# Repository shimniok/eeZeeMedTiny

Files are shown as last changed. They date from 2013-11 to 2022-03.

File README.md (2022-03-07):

# eeZeeMedTiny
A breadboard breakout / target board for ATtiny84 family

The smallest breakout & target board for the 14-pin ATtiny84, including AVR ISP header, reset switch and pull-up resistor,
and bypass caps. Step up to an ATtiny84 for more power and 6 more pins.

Easy to breadboard, prototype and program ATtiny84 with eeZee Medium Tiny. 

[For sale on Tindie.com](https://www.tindie.com/products/bot_thoughts/attiny84-development-board/)

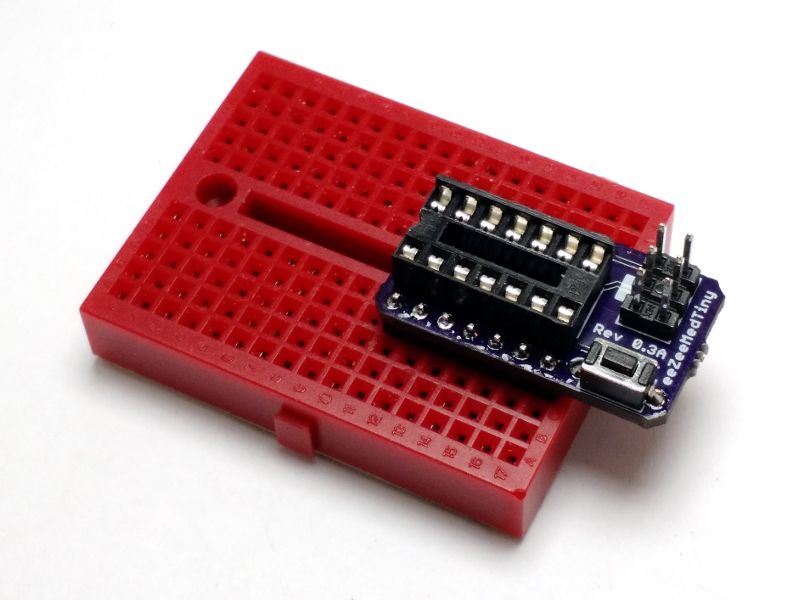
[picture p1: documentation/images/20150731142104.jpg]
top view


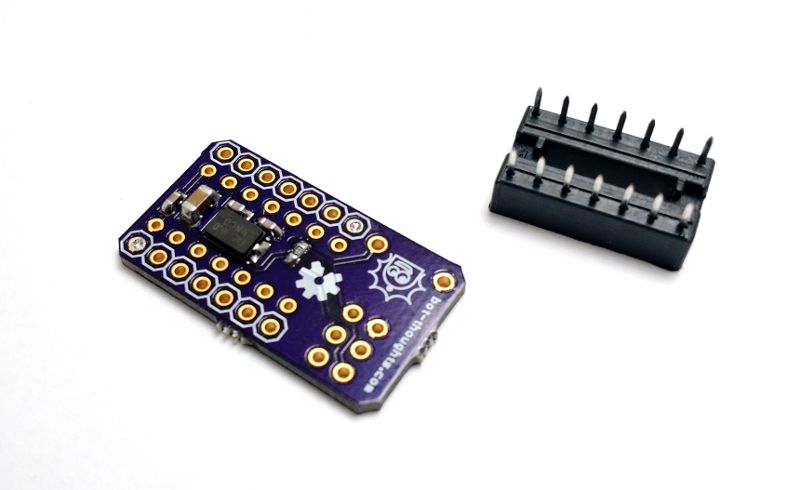
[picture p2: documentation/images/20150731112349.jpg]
bottom view


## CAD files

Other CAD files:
electronics/eeZee_medium_tiny.skp

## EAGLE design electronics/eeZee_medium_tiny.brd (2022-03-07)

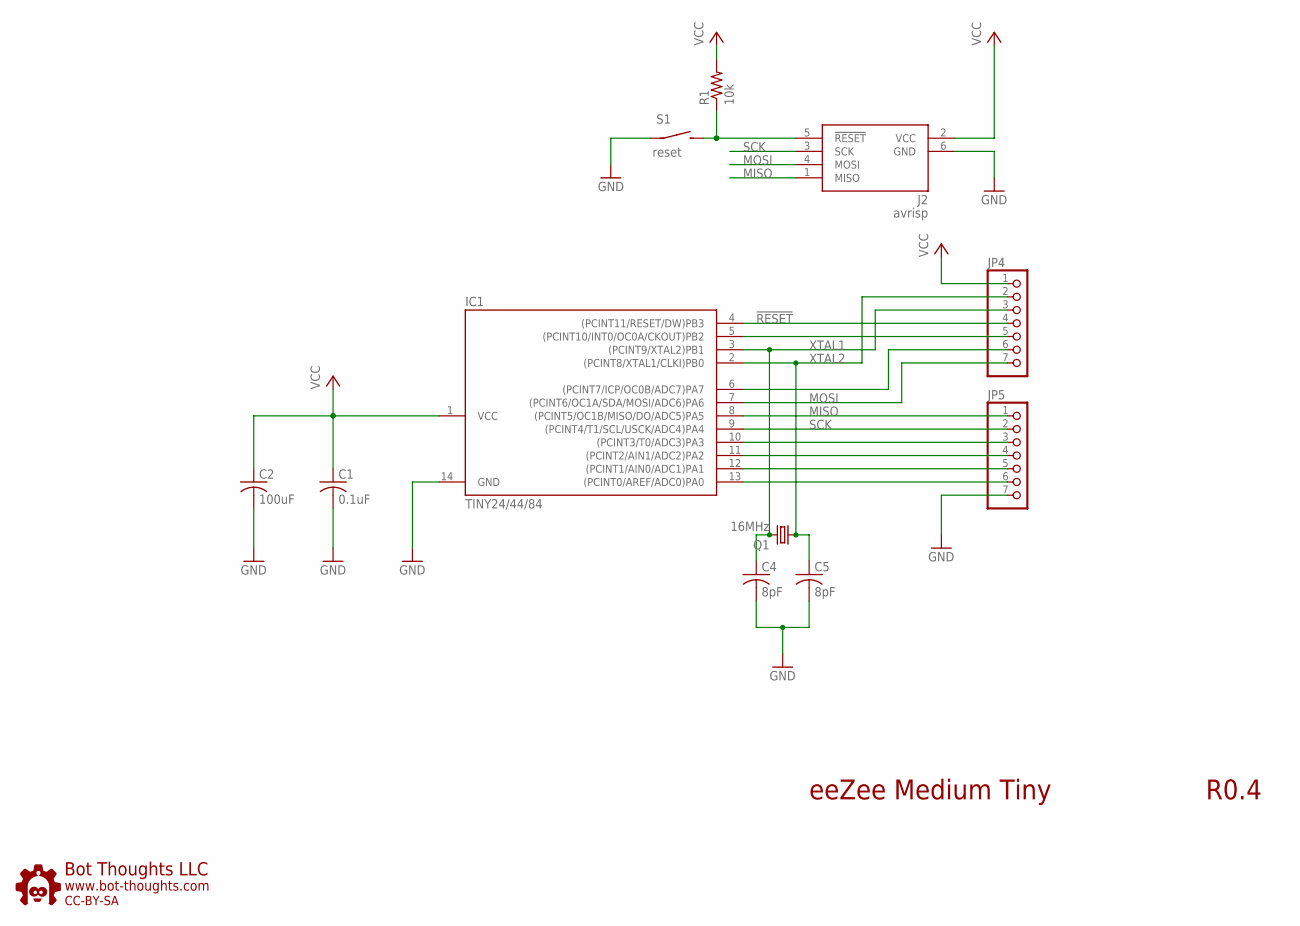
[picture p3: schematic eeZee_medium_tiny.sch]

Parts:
C1: 0.1uF; C0603; PARTNO 0603YC104KAT2A
C2: 100uF; C1206; PARTNO MCTT21X106M6R3CT
C4, C5: 8pF; C0603; PARTNO 0603YC104KAT2A
IC1: TINY24/44/84; DIL14
J2: avrisp; CON6P2R
JP4, JP5: PINHD-1X07_2.54-S; 1X07-S
Q1: 16MHz; NDK_2PAD_5X3
R1: 10k; R0603; PARTNO ERJ-3GEYJ103V
S1: reset; 6MMTACTILE_RECT
U$1: BTLOGO-LOGO-SM; BTLOGOS

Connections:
!RESET: IC1.4 ((PCINT11/RESET/DW)PB3), J2.5 (!RESET), JP4.4, R1.1, S1.P$2 (S)
GND: C1.2, C2.2, C4.2, C5.2, IC1.14 (GND), J2.6 (GND), JP5.7, S1.P$1
MISO: IC1.8 ((PCINT5/OC1B/MISO/DO/ADC5)PA5), J2.1 (MISO), JP5.1
MOSI: IC1.7 ((PCINT6/OC1A/SDA/MOSI/ADC6)PA6), J2.4 (MOSI), JP4.7
unnamed: IC1.5 ((PCINT10/INT0/OC0A/CKOUT)PB2), JP4.5
unnamed: IC1.6 ((PCINT7/ICP/OC0B/ADC7)PA7), JP4.6
unnamed: IC1.10 ((PCINT3/T0/ADC3)PA3), JP5.3
unnamed: IC1.11 ((PCINT2/AIN1/ADC2)PA2), JP5.4
unnamed: IC1.12 ((PCINT1/AIN0/ADC1)PA1), JP5.5
unnamed: IC1.13 ((PCINT0/AREF/ADC0)PA0), JP5.6
SCK: IC1.9 ((PCINT4/T1/SCL/USCK/ADC4)PA4), J2.3 (SCK), JP5.2
VCC: C1.1, C2.1, IC1.1 (VCC), J2.2 (VCC), JP4.1, R1.2
XTAL1: C5.1, IC1.2 ((PCINT8/XTAL1/CLKI)PB0), JP4.2, Q1.P$1 (1)
XTAL2: C4.1, IC1.3 ((PCINT9/XTAL2)PB1), JP4.3, Q1.P$2 (2)

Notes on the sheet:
eeZee Medium Tiny
R0.4

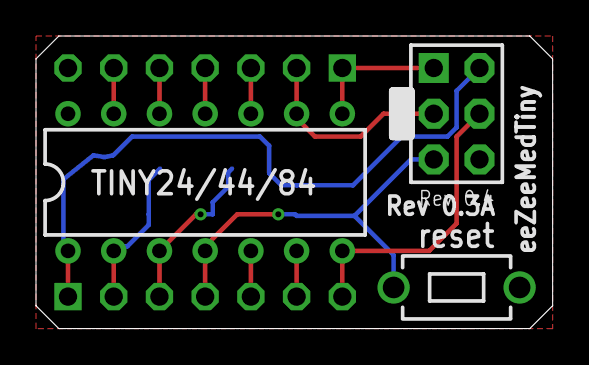
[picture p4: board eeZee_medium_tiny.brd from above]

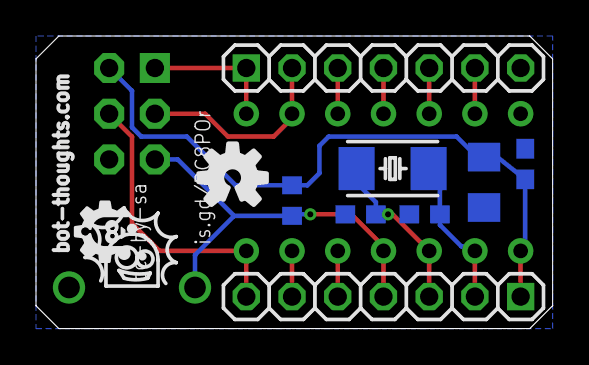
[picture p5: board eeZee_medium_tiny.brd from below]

Board: 2 copper layers, 28.7 x 16.3 mm, 12 parts (9 on the bottom side), 14 nets.

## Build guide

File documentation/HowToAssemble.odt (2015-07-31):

Assembly Instructions for eeZee Medium Tiny

Assembling your eeZee Medium Tiny is easy. And, you can learn how to solder at the same time. Review Sparkfun's Soldering Tutorial (https://learn.sparkfun.com/tutorials/how-to-solder---through-hole-soldering) if you need to. Here's a helpful info-graphic from the tutorial:

Illustration 1: https://learn.sparkfun.com/tutorials/how-to-solder---through-hole-soldering

# You'll need

- Soldering iron, 40W
- Sponge to clean the iron (I recommend a brass sponge)
- Workbench with plenty of light
- Ventilation since breathing flux fumes is irritating
- Soldering surface (e.g., marble tile sample)
- Rosin core solder 0.022” or 0.032” diameter
- Kester #2331-ZX flux pen (optional)

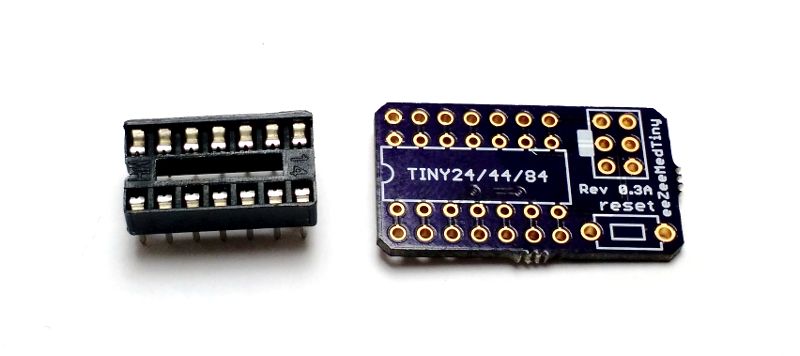
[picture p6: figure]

IC Socket

Apply flux pen or flux paste to the pin pads, top and bottom.

Match the notch on the socket with the silkscreen on the board

Insert the socket and flip the board and socket upside down

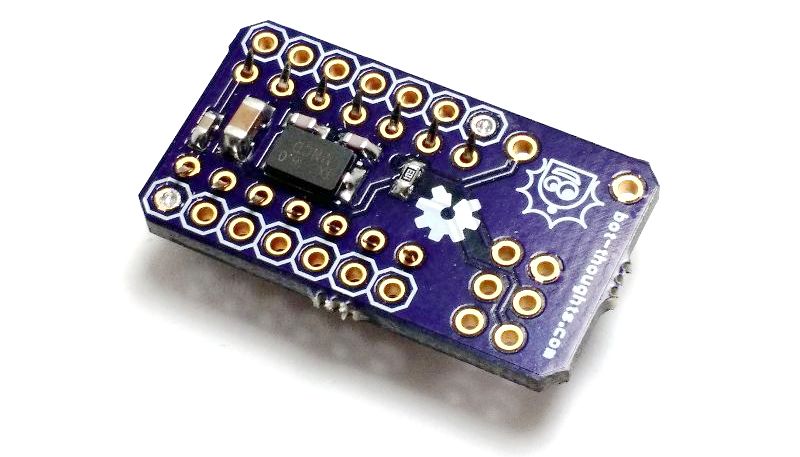
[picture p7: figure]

Bend the socket pins outward to help hold the socket and board together

Solder a pin in one corner, then a pin in the opposite corner

Solder the remaining pins

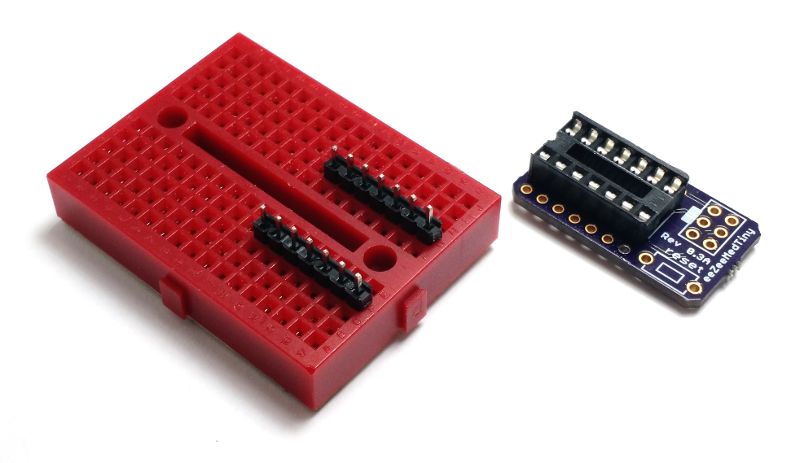
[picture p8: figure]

Pin Headers

Stick the two 4-pin headers into your breadboard, long side down, with 4 rows between

Apply flux to the outer pin header pads

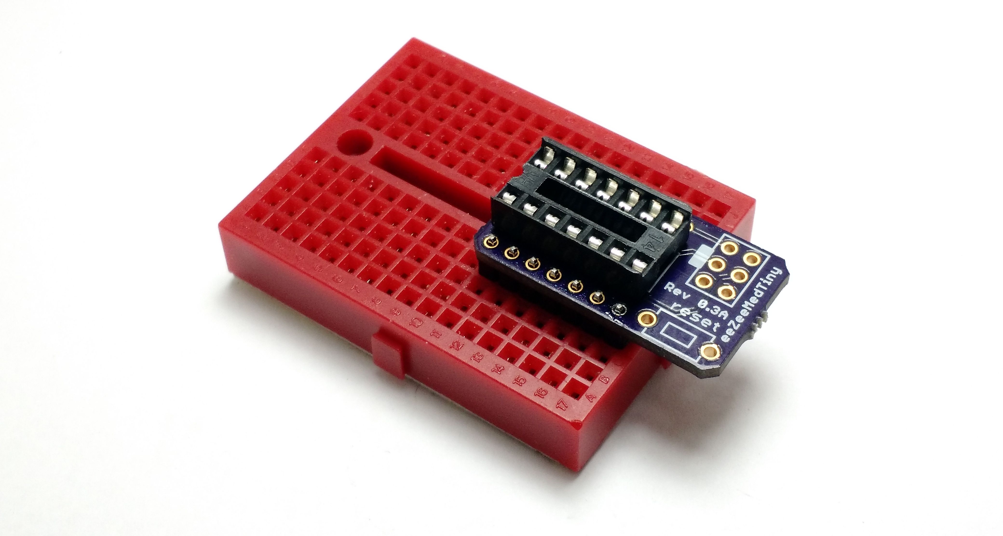
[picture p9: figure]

Place eeZeeTiny onto to pin headers

Holding the board in place, solder one of the pins on each pin header

Now solder the rest of the pins

ISP Header

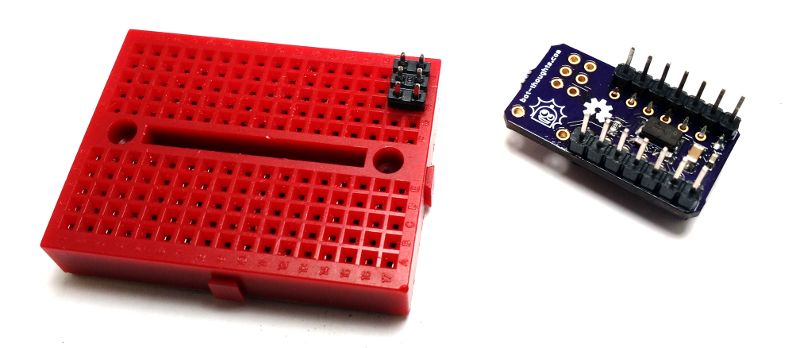
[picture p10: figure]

Install the 2x3 ISP header into the breadboard, long side down

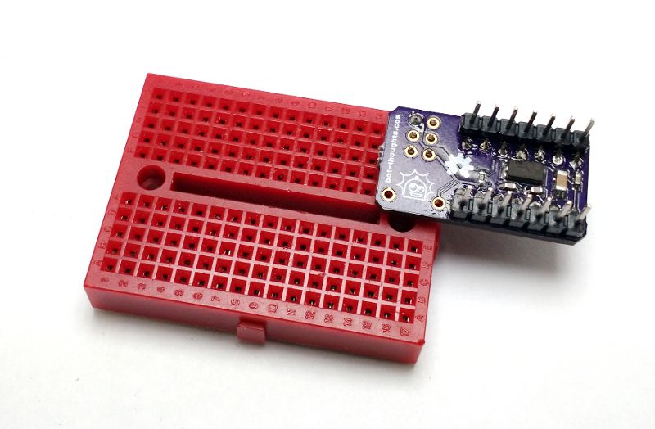
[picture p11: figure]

Flip the board upside down and place the board onto the pin header

Hold down the board and solder one pin

Solder the remaining pins.

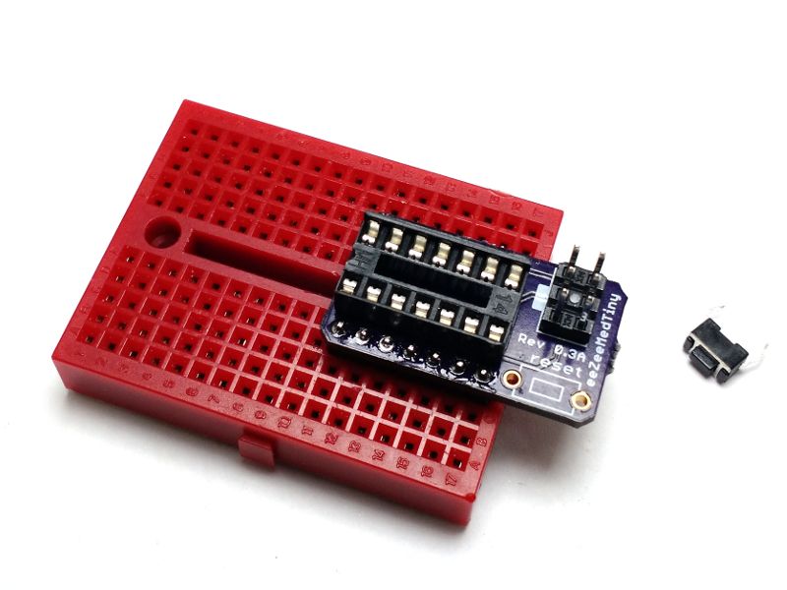
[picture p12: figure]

Reset Switch

Insert the board back into the breadboard, right side up

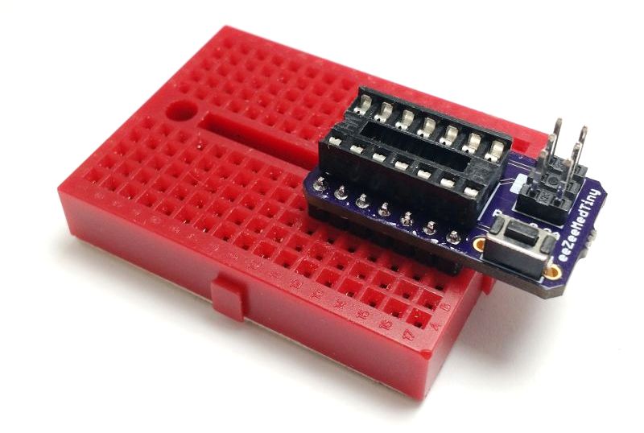
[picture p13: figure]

Install the reset switch

Solder the reset switch pins on the top side

Flip the board upside down and solder the reset switch on the bottom side

Cleanup

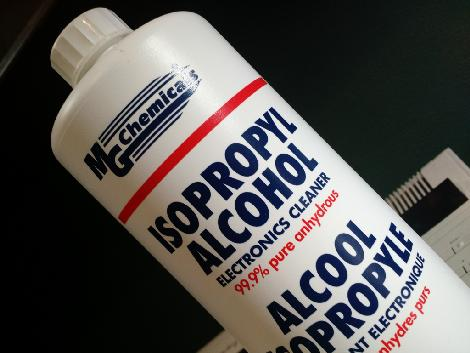
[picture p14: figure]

You'll want to remove the rosin and flux

I usually just use isopropyl alcohol and an old toothbrush

You can also buy chemicals specifically for removing flux and rosin

eeZeeTiny Assembly Instructions

www.bot-thoughts.com Page 4 / 4 Bot Thoughts LLC

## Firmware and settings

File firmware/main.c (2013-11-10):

/** ATtiny84 test
 * 
 * Author: Michael Shimniok (www.bot-thoughts.com)
 * Description: Sequentially turns on a single pin on PA0-7 and PB0-2 (PB3 is reset)
 *
 */
#include <avr/io.h>
#include <avr/interrupt.h>
#include <util/delay.h>

int main()
{
  char i;

  PORTA=0;
  PORTB=0;
  DDRA=0xff;   // All PORTA as output
  DDRB=0x07;   // PB0-2, PB3 is reset

  while (1) {
    for (i = 0 ; i < 8; i++) {
      PORTA = (1 << i);
      _delay_ms(300);
    }
    PORTA = 0;

    for (i = 2; i < 3; i++) {
      PORTB = (1 << i);
      _delay_ms(300);
    }
    PORTB = 0;
  }

}

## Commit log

2013-01-08 Initial revision
    [eeZee_big_tiny.brd, eeZee_big_tiny.sch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]
2013-01-08 Renamed files
    [eeZee_medium_tiny.brd]
2013-01-08 Minor board tweaks
    [eeZee_medium_tiny.brd]
2013-08-06 Rev 0.2 as ordered, mitered corners, flipped tantalum and added polarity silk screen, changed location of caps/crystals for easier assembly, shrunk board size.
    [eeZee_medium_tiny.brd, eeZee_medium_tiny.sch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]
2013-11-10 Created electronics and firmware directories so I could host example code.
    [eeZee_medium_tiny.brd, eeZee_medium_tiny.sch, eeZee_medium_tiny.skp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]
2014-04-15 Revised pads for IC, revised 10uF filtering cap footprint to 1206.
    [eeZee_medium_tiny.brd, eeZee_medium_tiny.sch]
2014-04-15 Removed extraneous silkscreen
    [eeZee_medium_tiny.brd]
2014-10-17 Changed spacing to 10mil/8mil, relocated too-close traces, relocated via
    [eeZee_medium_tiny.brd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]
2015-07-31 Added assembly instructions
2022-03-07 update logo, silk, add help url
    [eeZee_medium_tiny.brd, eeZee_medium_tiny.sch]
2022-03-07 updated gerbers, zip
2022-03-07 switched pics for better ones

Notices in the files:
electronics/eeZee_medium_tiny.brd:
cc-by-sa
